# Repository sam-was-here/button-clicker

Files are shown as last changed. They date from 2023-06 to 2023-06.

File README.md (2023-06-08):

# Button Clicker

This repository contains the project files for an electronic button clicker. A button clicker is a small electronic device that counts how many times the button on the device has been pressed. It features an additional button that displays the count on the device to save battery power. The maximum count on the device is 999,999, and it has a button debounce time of approximately 10ms. The counting mechanism utilizes BCD counters, and the count is displayed on 7-segment displays using a BCD to 7-segment IC. The device itself has dimensions of approximately 4 x 1 x 0.65 inches and comes with a 3D-printed case designed to hold the PCB. The PCB is a 2-layered board with a trace width and spacing of 0.15mm. Most components are surface mount devices (SMD), except for the buttons and displays. To ensure accurate functionality, it is recommended to add shielding inside the case; otherwise, the button clicker may randomly count up, reset, or count down. The electronics design was created using KiCad, while the case was made using FreeCAD. All design files are included in the repository, allowing for modifications if desired.

## Images







## Bill of Materials (BOM)

- BT1: 3034TR - CR2032 battery holder - [Digi-Key Link](https://www.digikey.com/short/wqhf8fbf)
- C1-C11: 0603 0.1uF ceramic capacitor - bypass capacitor
- D1: SOD-523 - Crowbar diode for reverse polarity protection
- D2-D5: SMA - TVS diode - [Mouser Link](https://mou.sr/43r05RL)
- R1-R5: 0603 100k 5% resistor - button pull-up/down resistors and debouncing
- R6-R47: 0603 1k 5% resistor - LED current limiting resistors
- SW1: THT tack switch right angle - button for counting clicks - [Mouser Link](https://mou.sr/42t1Exi)
- SW2: THT tack switch right angle - button to light up display - [Mouser Link](https://mou.sr/42t1Exi)
- SW3: SMD tack switch - reset button - [Mouser Link](https://mou.sr/3oV6upt)
- U1: SOT-23 (5) 74LVC1G17 - Single Schmitt-Trigger Buffer - [Digi-Key Link](https://www.digikey.com/short/7bh4nv4q)
- U2-U4: TSSOP-16 74HC390 - Dual Decade RPL Counter - [Mouser Link](https://mou.sr/3katv4U)
- U5-U10: TSSOP-16 74HC4511 - BCD-to-7 Segment - [Digi-Key Link](https://www.digikey.com/short/bz3pz8r9)
- U11-U16: INND-TS30RCB - Red 7-segment display - [Digi-Key Link](https://www.digikey.com/short/40qw31cv)

## Schematic

Schematic

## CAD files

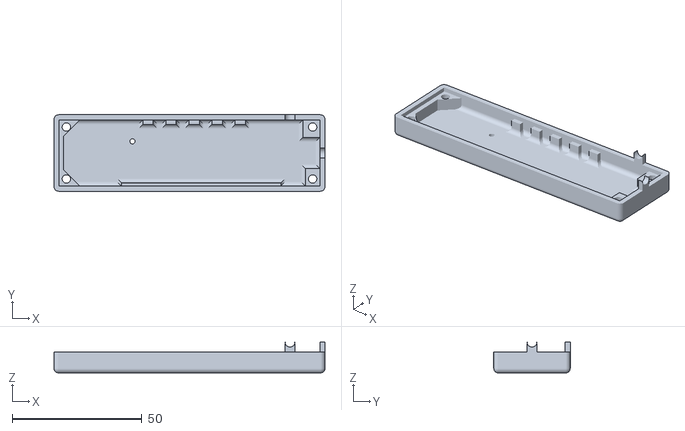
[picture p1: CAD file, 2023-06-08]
case/clicker-counter-case-bottom.stl
104.5 x 29.5 x 11.9

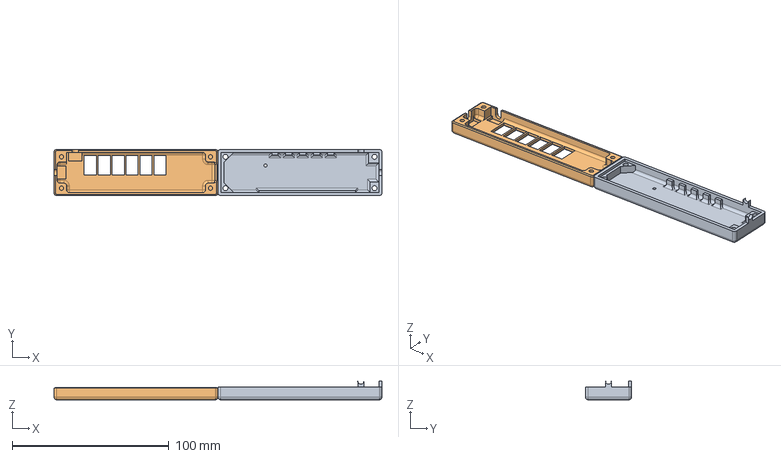
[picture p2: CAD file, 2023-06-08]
case/clicker-counter-case.FCStd
209.0 x 29.5 x 11.9 mm

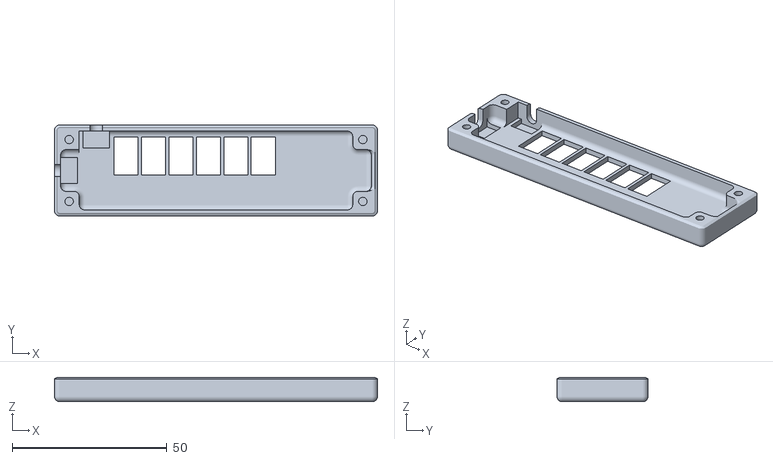
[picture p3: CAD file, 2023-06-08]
case/clicker-counter-case-top.stl
104.5 x 29.5 x 7.90

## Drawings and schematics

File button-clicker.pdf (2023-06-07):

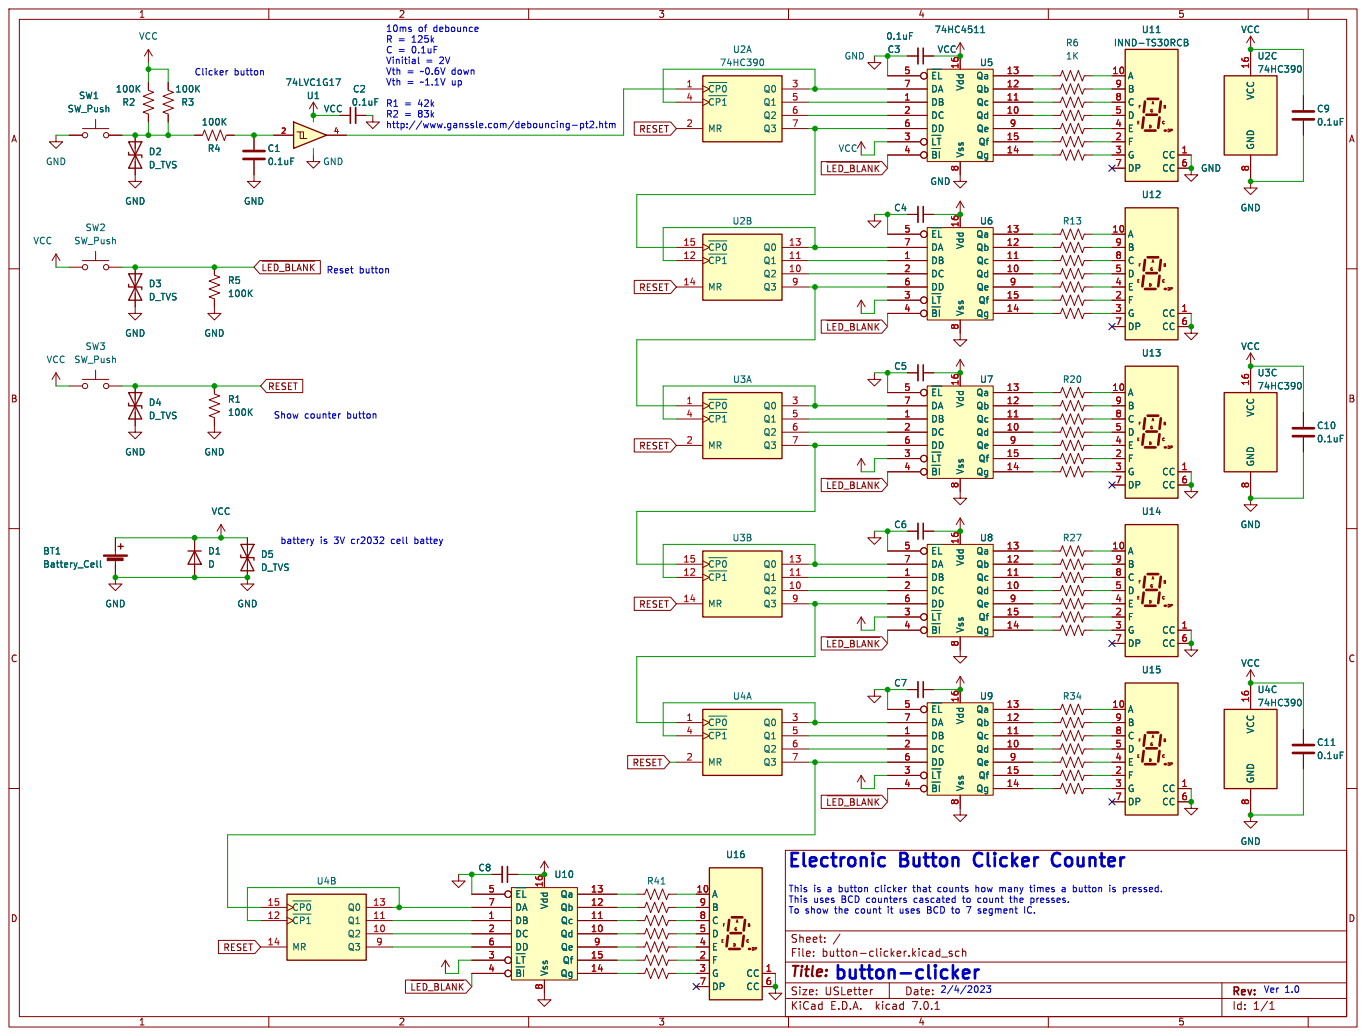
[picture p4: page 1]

Vth = ~0.6V down Vth = ~1.1V up R1 = 42k R2 = 83k http://www.ganssle.com/debouncing-pt2.htm

battery is 3V cr2032 cell battey Show counter button

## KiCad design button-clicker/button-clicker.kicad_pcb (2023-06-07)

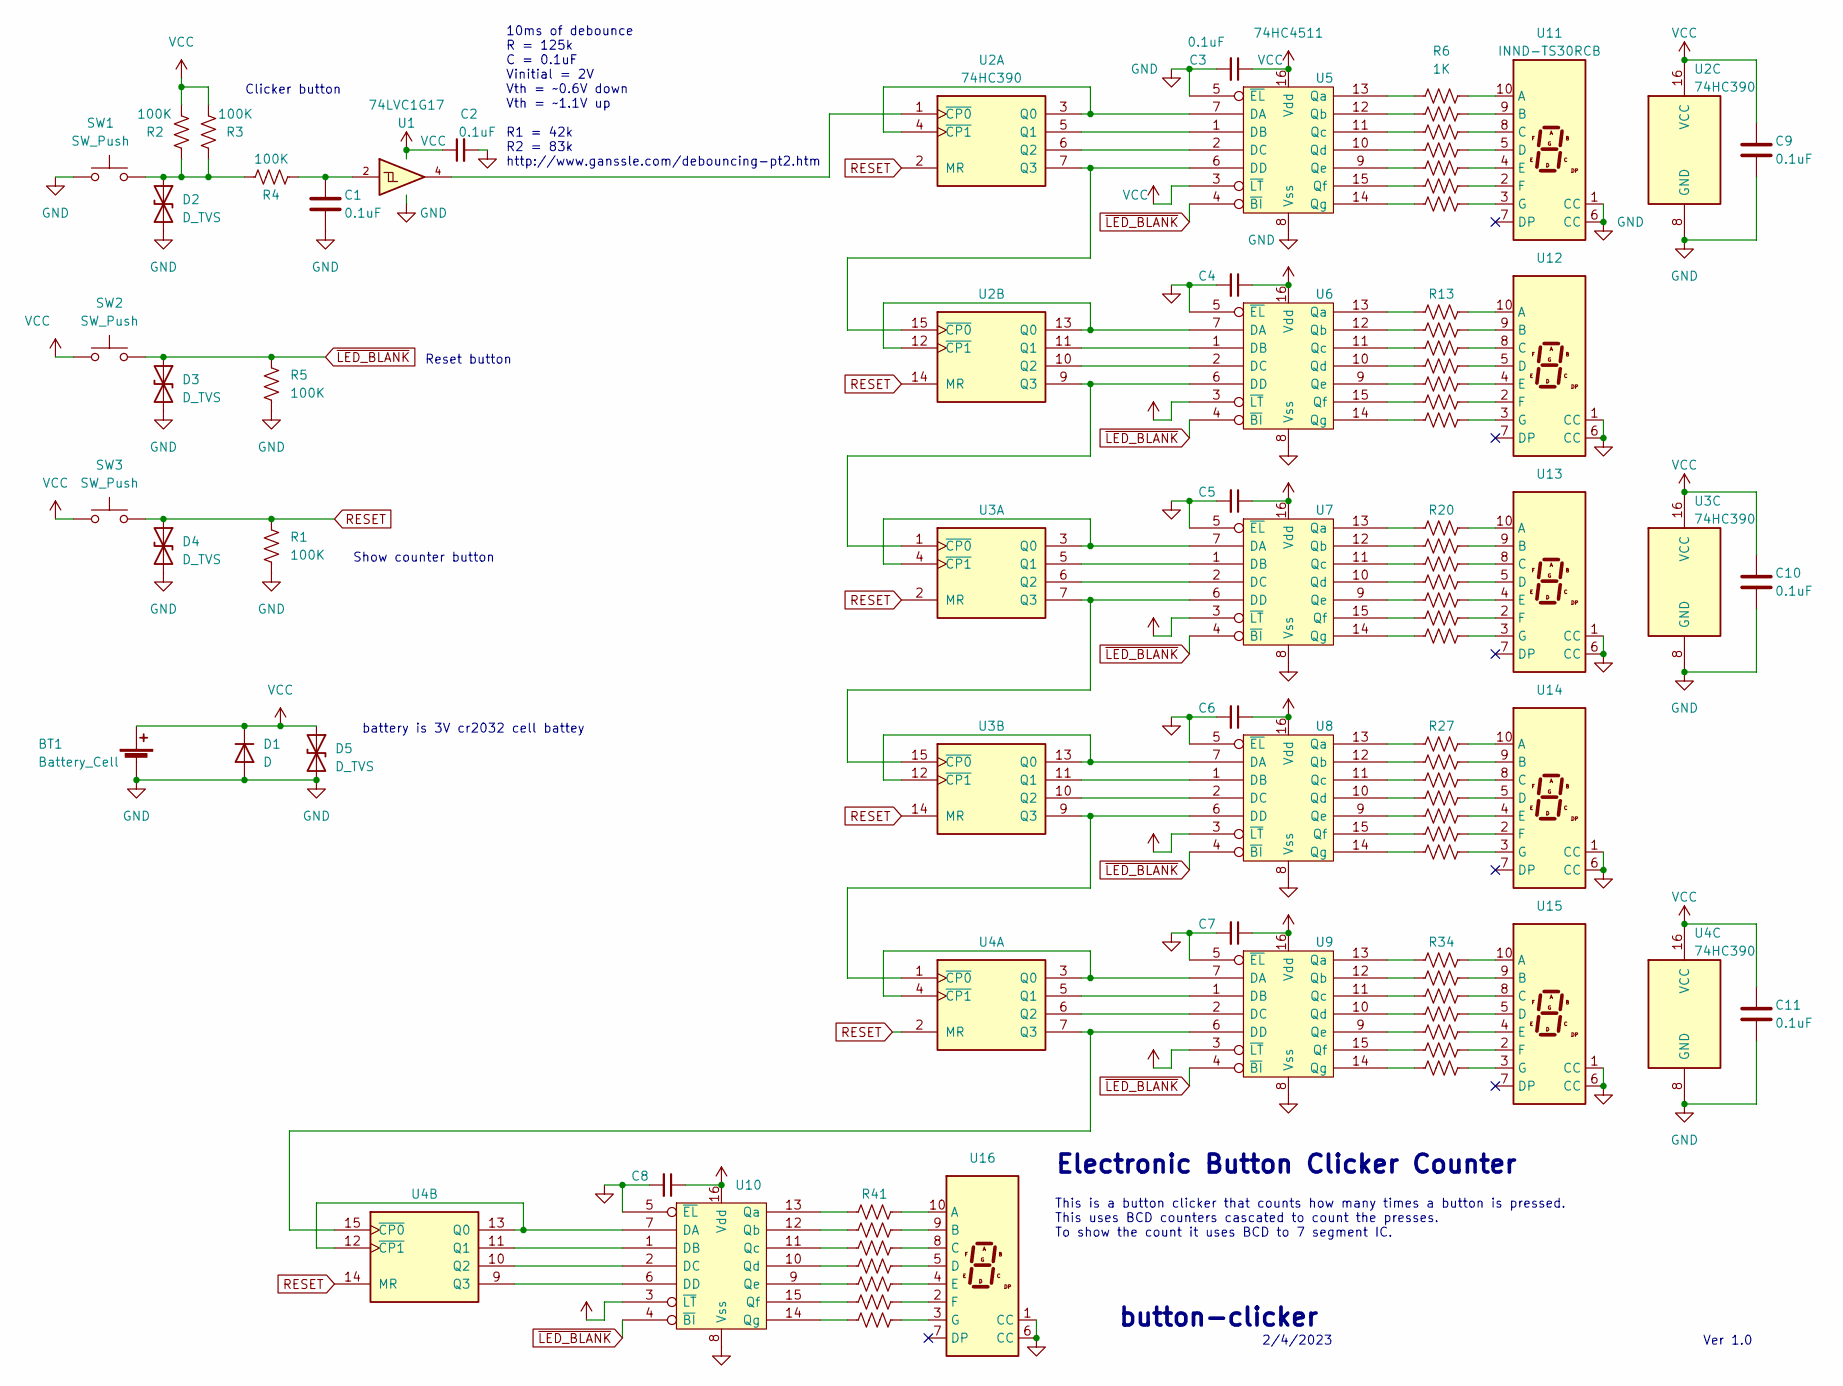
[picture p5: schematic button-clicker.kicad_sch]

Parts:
BT1: Battery_Cell; BatteryHolder_Keystone_3034_1x20mm
C1, C2, C3, C4, C5, C6, C7, C8, C9, C10, C11: 0.1uF; C_0603_1608Metric; JLC 0603
D1: D; D_SMA
D2, D3, D4, D5: D_TVS; D_SOD-523
R1, R2, R3, R4, R5: 100K; R_0603_1608Metric; JLC 0603
R6, R7, R8, R9, R10, R11, R12, R13, R14, R15, R16, R17, R18, R19, R20, R21, R22, R23, R24, R25, R26, R27, R28, R29, R30, R31, R32, R33, R34, R35, R36, R37, R38, R39, R40, R41, R42, R43, R44, R45, R46, R47: 1K; R_0603_1608Metric; JLC 0603
SW1: SW_Push; SW_Tactile_SPST_Angled_PTS645Vx83-2LFS
SW2: SW_Push; SW_Tactile_SPST_Angled_PTS645Vx39-2LFS
SW3: SW_Push; SW_Push_1P1T_NO_Vertical_Wuerth_434133025816
U1: 74LVC1G17; SOT-23-5
U2, U3, U4: 74HC390; TSSOP-16_4.4x5mm_P0.65mm
U5, U6, U7, U8, U9, U10: 74HC4511; TSSOP-16_4.4x5mm_P0.65mm
U11, U12, U13, U14, U15, U16: INND-TS30RCB; HDSP-A151

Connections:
GND: BT1.2 (-), C1.2, C2.2, C3.2, C4.2, C5.2, C6.2, C7.2, C8.2, C9.2, C10.2, C11.2, D1.2 (A), D2.2 (A2), D3.2 (A2), D4.2 (A2), D5.2 (A2), R1.2, R5.2, SW1.1, U1.3 (GND), U2.8 (GND), U3.8 (GND), U4.8 (GND), U5.5 (~EL), U5.8 (Vss), U6.5 (~EL), U6.8 (Vss), U7.5 (~EL), U7.8 (Vss), U8.5 (~EL), U8.8 (Vss), U9.5 (~EL), U9.8 (Vss), U10.5 (~EL), U10.8 (Vss), U11.1 (CC), U11.6 (CC), U12.1 (CC), U12.6 (CC), U13.1 (CC), U13.6 (CC), U14.1 (CC), U14.6 (CC), U15.1 (CC), U15.6 (CC), U16.1 (CC), U16.6 (CC)
unnamed: C1.1, R4.2, U1.2
unnamed: D2.1 (A1), R2.2, R3.1, R4.1, SW1.2
unnamed: U2.3 (Q0), U2.4 (~CP1), U5.7 (DA)
unnamed: U2.5 (Q1), U5.1 (DB)
unnamed: U2.6 (Q2), U5.2 (DC)
unnamed: U2.7 (Q3), U2.15 (~CP0), U5.6 (DD)
unnamed: U1.4, U2.1 (~CP0)
unnamed: U2.12 (~CP1), U2.13 (Q0), U6.7 (DA)
unnamed: U2.11 (Q1), U6.1 (DB)
unnamed: U2.10 (Q2), U6.2 (DC)
unnamed: U2.9 (Q3), U3.1 (~CP0), U6.6 (DD)
unnamed: U3.3 (Q0), U3.4 (~CP1), U7.7 (DA)
unnamed: U3.5 (Q1), U7.1 (DB)
unnamed: U3.6 (Q2), U7.2 (DC)
unnamed: U3.7 (Q3), U3.15 (~CP0), U7.6 (DD)
unnamed: U3.12 (~CP1), U3.13 (Q0), U8.7 (DA)
unnamed: U3.11 (Q1), U8.1 (DB)
unnamed: U3.10 (Q2), U8.2 (DC)
unnamed: U3.9 (Q3), U4.1 (~CP0), U8.6 (DD)
unnamed: U4.3 (Q0), U4.4 (~CP1), U9.7 (DA)
unnamed: U4.5 (Q1), U9.1 (DB)
unnamed: U4.6 (Q2), U9.2 (DC)
unnamed: U4.7 (Q3), U4.15 (~CP0), U9.6 (DD)
unnamed: R6.1, U5.13 (Qa)
unnamed: R7.1, U5.12 (Qb)
unnamed: R8.1, U5.11 (Qc)
unnamed: R9.1, U5.10 (Qd)
unnamed: R10.1, U5.9 (Qe)
unnamed: R11.1, U5.15 (Qf)
unnamed: R12.1, U5.14 (Qg)
unnamed: R13.1, U6.13 (Qa)
unnamed: R14.1, U6.12 (Qb)
unnamed: R15.1, U6.11 (Qc)
unnamed: R16.1, U6.10 (Qd)
unnamed: R17.1, U6.9 (Qe)
unnamed: R18.1, U6.15 (Qf)
unnamed: R19.1, U6.14 (Qg)
unnamed: R20.1, U7.13 (Qa)
unnamed: R21.1, U7.12 (Qb)
unnamed: R22.1, U7.11 (Qc)
unnamed: R23.1, U7.10 (Qd)
unnamed: R24.1, U7.9 (Qe)
unnamed: R25.1, U7.15 (Qf)
unnamed: R26.1, U7.14 (Qg)
unnamed: R27.1, U8.13 (Qa)
unnamed: R28.1, U8.12 (Qb)
unnamed: R29.1, U8.11 (Qc)
unnamed: R30.1, U8.10 (Qd)
unnamed: R31.1, U8.9 (Qe)
unnamed: R32.1, U8.15 (Qf)
unnamed: R33.1, U8.14 (Qg)
unnamed: R34.1, U9.13 (Qa)
unnamed: R35.1, U9.12 (Qb)
unnamed: R36.1, U9.11 (Qc)
unnamed: R37.1, U9.10 (Qd)
unnamed: R38.1, U9.9 (Qe)
unnamed: R39.1, U9.15 (Qf)
unnamed: R40.1, U9.14 (Qg)
unnamed: U4.12 (~CP1), U4.13 (Q0), U10.7 (DA)
unnamed: U4.11 (Q1), U10.1 (DB)
unnamed: U4.10 (Q2), U10.2 (DC)
unnamed: U4.9 (Q3), U10.6 (DD)
unnamed: R41.1, U10.13 (Qa)
unnamed: R42.1, U10.12 (Qb)
unnamed: R43.1, U10.11 (Qc)
unnamed: R44.1, U10.10 (Qd)
unnamed: R45.1, U10.9 (Qe)
unnamed: R46.1, U10.15 (Qf)
unnamed: R47.1, U10.14 (Qg)
unnamed: R6.2, U11.10 (A)
unnamed: R7.2, U11.9 (B)
unnamed: R8.2, U11.8 (C)
unnamed: R9.2, U11.5 (D)
unnamed: R10.2, U11.4 (E)
unnamed: R11.2, U11.2 (F)
unnamed: R12.2, U11.3 (G)
unnamed: R13.2, U12.10 (A)
unnamed: R14.2, U12.9 (B)
unnamed: R15.2, U12.8 (C)
unnamed: R16.2, U12.5 (D)
unnamed: R17.2, U12.4 (E)
unnamed: R18.2, U12.2 (F)
unnamed: R19.2, U12.3 (G)
unnamed: R20.2, U13.10 (A)
unnamed: R21.2, U13.9 (B)
unnamed: R22.2, U13.8 (C)
unnamed: R23.2, U13.5 (D)
unnamed: R24.2, U13.4 (E)
unnamed: R25.2, U13.2 (F)
unnamed: R26.2, U13.3 (G)
unnamed: R27.2, U14.10 (A)
unnamed: R28.2, U14.9 (B)
unnamed: R29.2, U14.8 (C)
unnamed: R30.2, U14.5 (D)
unnamed: R31.2, U14.4 (E)
unnamed: R32.2, U14.2 (F)
unnamed: R33.2, U14.3 (G)
unnamed: R34.2, U15.10 (A)
unnamed: R35.2, U15.9 (B)
unnamed: R36.2, U15.8 (C)
unnamed: R37.2, U15.5 (D)
unnamed: R38.2, U15.4 (E)
unnamed: R39.2, U15.2 (F)
unnamed: R40.2, U15.3 (G)
unnamed: R41.2, U16.10 (A)
unnamed: R42.2, U16.9 (B)
unnamed: R43.2, U16.8 (C)
unnamed: R44.2, U16.5 (D)
unnamed: R45.2, U16.4 (E)
unnamed: R46.2, U16.2 (F)
unnamed: R47.2, U16.3 (G)
RESET: D4.1 (A1), R1.1, SW3.2, U2.2 (MR), U2.14 (MR), U3.2 (MR), U3.14 (MR), U4.2 (MR), U4.14 (MR)
VCC: BT1.1 (+), C2.1, C3.1, C4.1, C5.1, C6.1, C7.1, C8.1, C9.1, C10.1, C11.1, D1.1 (K), D5.1 (A1), R2.1, R3.2, SW2.1, SW3.1, U1.5 (VCC), U2.16 (VCC), U3.16 (VCC), U4.16 (VCC), U5.3 (~LT), U5.16 (Vdd), U6.3 (~LT), U6.16 (Vdd), U7.3 (~LT), U7.16 (Vdd), U8.3 (~LT), U8.16 (Vdd), U9.3 (~LT), U9.16 (Vdd), U10.3 (~LT), U10.16 (Vdd)
~LED_BLANK: D3.1 (A1), R5.1, SW2.2, U5.4 (~BI), U6.4 (~BI), U7.4 (~BI), U8.4 (~BI), U9.4 (~BI), U10.4 (~BI)

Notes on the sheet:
Clicker button
button-clicker
10ms of debounce R = 125k C = 0.1uF Vinitial = 2V Vth = ~0.6V down Vth = ~1.1V up R1 = 42k R2 = 83k http://www.ganssle.com/debouncing-pt2.htm
This is a button clicker that counts how many times a button is pressed. This uses BCD counters cascated to count the presses. To show the count it uses BCD to 7 segment IC.
Reset button
Electronic Button Clicker Counter
battery is 3V cr2032 cell battey
2/4/2023
Show counter button
Ver 1.0

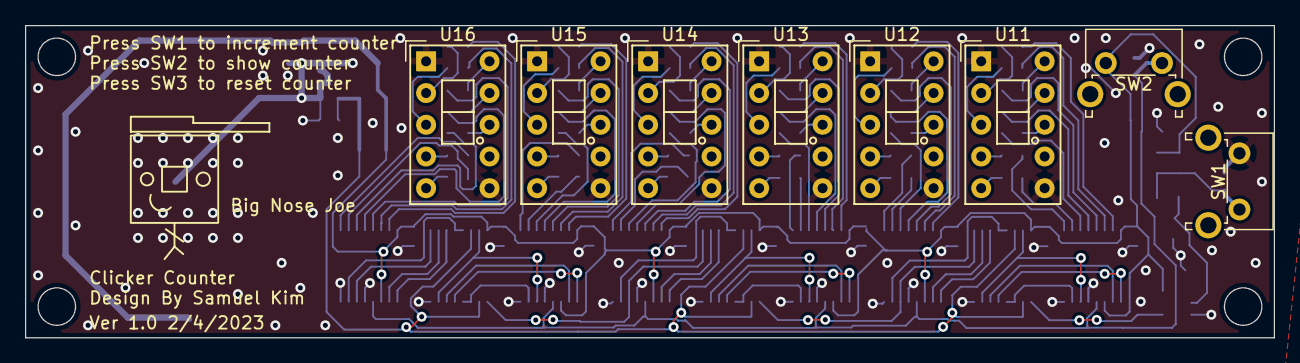
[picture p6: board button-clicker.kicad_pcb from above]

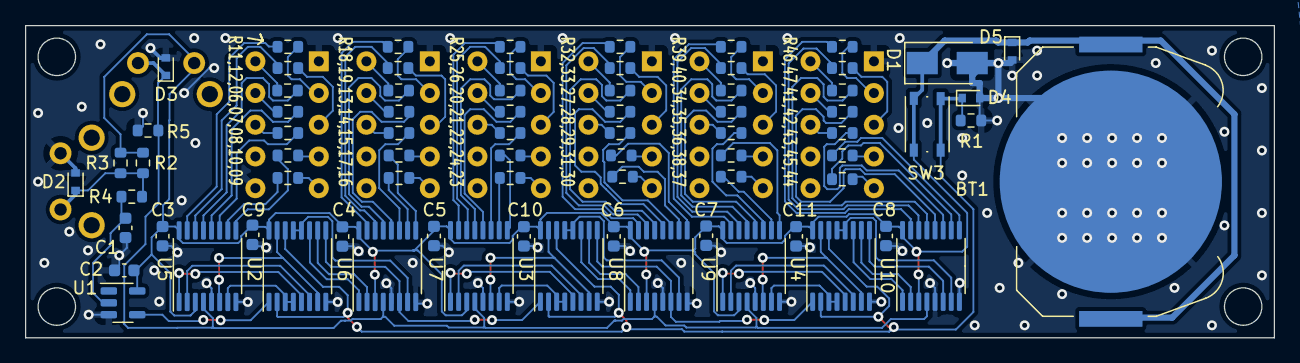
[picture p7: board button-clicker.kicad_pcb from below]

Board: 2 copper layers, 100.0 x 25.0 mm, 83 parts (75 on the bottom side), 115 nets.
